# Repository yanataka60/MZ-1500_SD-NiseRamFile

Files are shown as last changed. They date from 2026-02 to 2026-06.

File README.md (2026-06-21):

# MZ-1500_SD+偽RAMFILE複合ボード

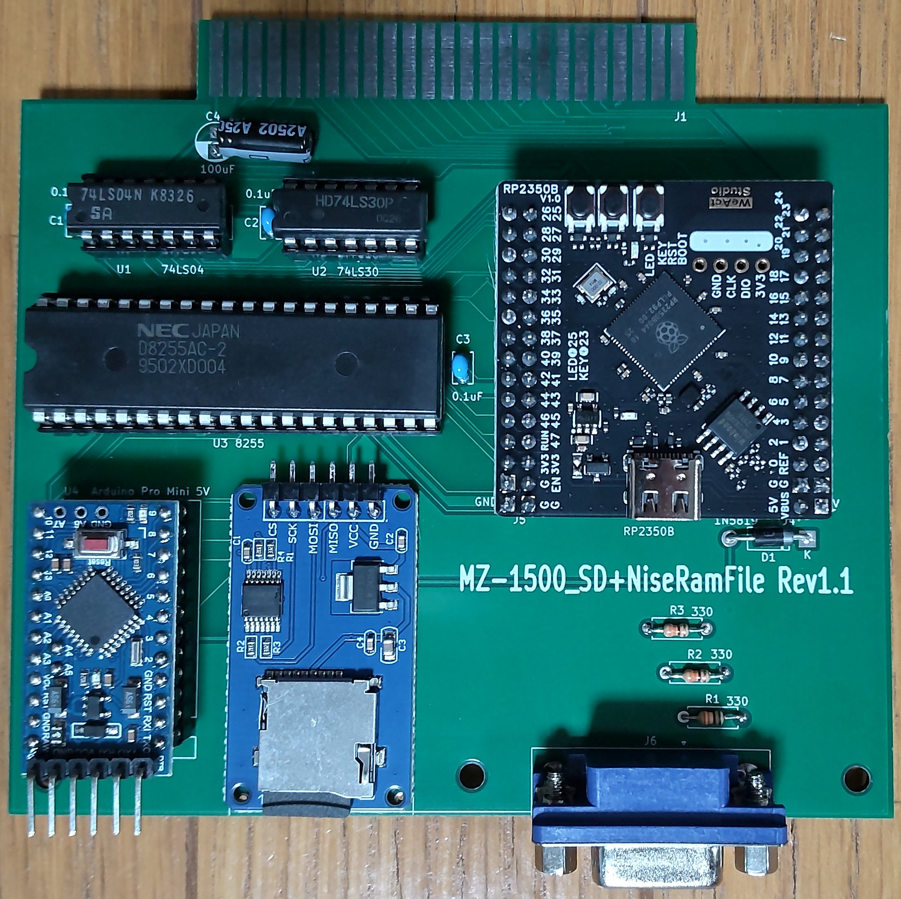
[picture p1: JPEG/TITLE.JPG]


しっぽいいんちょさんが作られた「偽RAMFILE for MZ-1500」とMZ-1500_SDを合体させたボードです。

MZ-1500_SD: https://github.com/yanataka60/MZ-1500_SD

偽RAMFILE for MZ-1500: https://github.com/shippoiincho/niseramfile

偽RAMFILE for MZ-1500のMZ-1R12 SRAMメモリをMZ-1500_SD起動用に使うことで一枚のボードにまとめています。

機能の詳細についてはそれぞれのウェブページを参照してください。

## 回路図
　KiCadフォルダ内のMZ-1500_SD+NRF.pdfを参照してください。

[回路図](https://github.com/yanataka60/MZ-1500_SD-NiseRamFile/blob/main/Kicad/MZ-1500_SD%2BNRF.pdf)

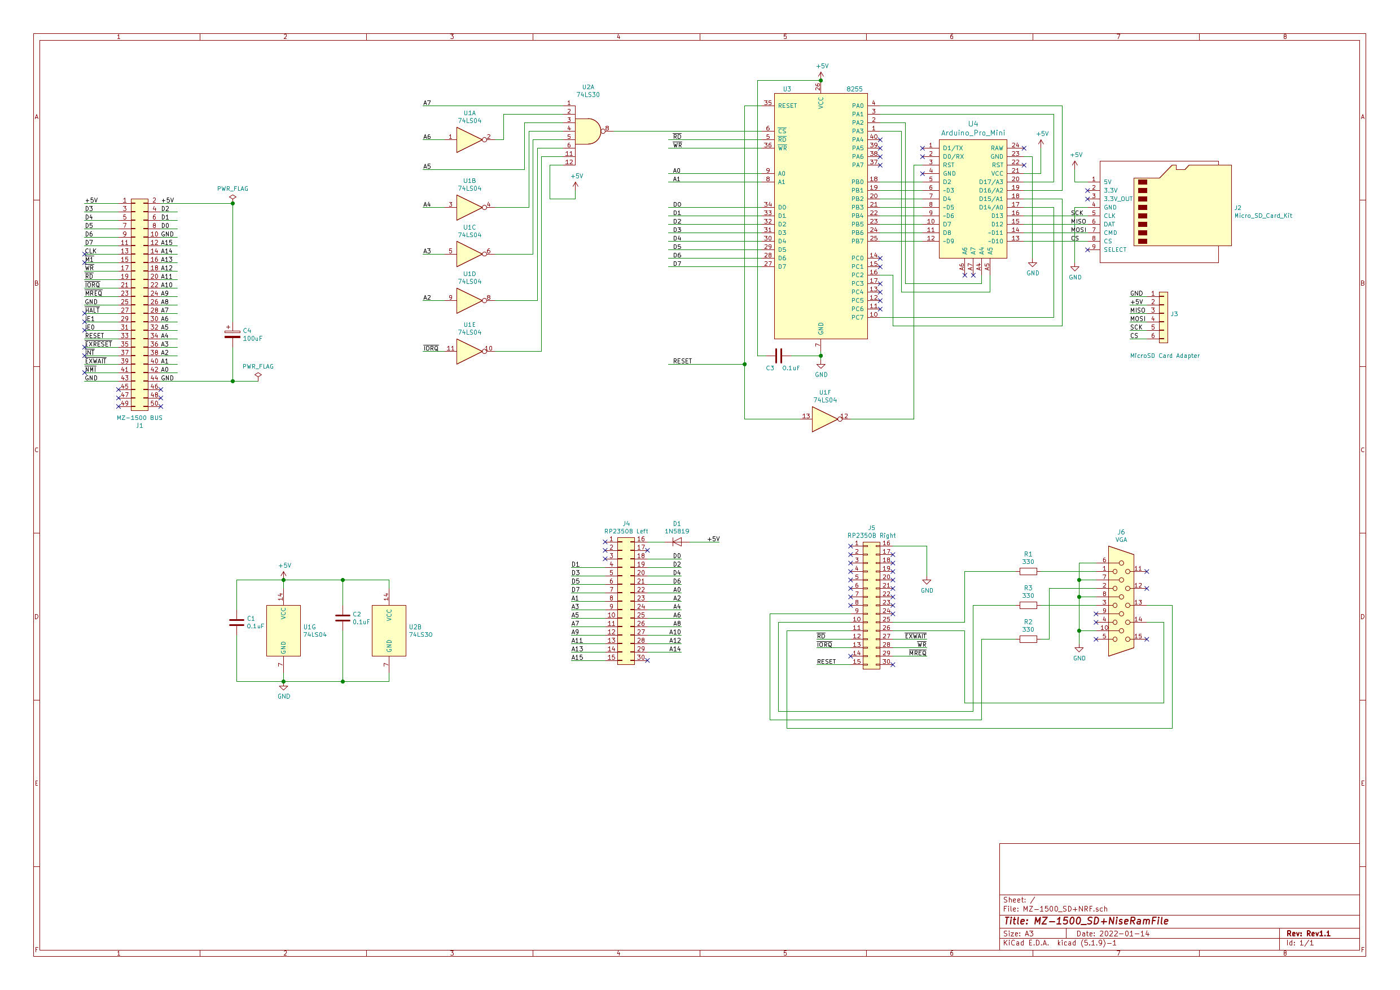
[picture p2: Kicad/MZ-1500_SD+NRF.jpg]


|番号|品名|数量|備考|
| --- | --- | --- | --- |
||J2、J3のいずれか|||
|J2|Micro_SD_Card_Kit|1|秋月電子通商 AE-microSD-LLCNV (注1)|
|J3|MicroSD Card Adapter|1|Arduino等に使われる5V電源に対応したもの(注3)|
|J4,J5|ピンソケット2x15Pin|2|RP2350Bマイコンボード用,秋月電子通商 FHU-2x42SGなど|
|J6|VGA用基板ソケット 3列15ピン|1|マルツ DJ-VGA14.5など(注4)|
|U1|74LS04|1||
|U2|74LS30|1||
|U3|8255|1||
|U4|Arduino_Pro_Mini_5V|1|Atmega328版を使用 168版は不可。(注2)|
||RP2350Bボード(Raspberry Pi Pico 2)|1|Amazon WA00021 RP2350Bマイコンボードなど|
|C1-C3|積層セラミックコンデンサ 0.1uF|3||
|C4|電解コンデンサ 16v100uF|1||
|D1|ダイオード 1N5819|1||
|R1-R3|カーボン抵抗 330Ω|3||
||ピンヘッダ|2Pin分|Arduino_Pro_MiniにはA4、A5用のピンヘッダが付いていないため別途調達が必要です 秋月電子通商 PH-1x40SGなど|
||ピンソケット(任意)|26Pin分|Arduino_Pro_Miniを取り外し可能としたい場合に調達します 秋月電子通商 FHU-1x42SGなど|

　　　注1)秋月電子通商　AE-microSD-LLCNVのJ1ジャンパはショートしてください。

　　　注2)Arduino Pro MiniはA4、A5ピンも使っています。

　　　注3)MicroSD Card Adapterを使う場合

　　　　　J3に取り付けます。

MicroSD Card Adapterについているピンヘッダを除去してハンダ付けするのが一番確実ですが、J3の穴にMicroSD Card Adapterをぴったりと押しつけ、裏から多めにハンダを流し込むことでハンダ付けをする方法もあります。なお、この方法の時にはしっかりハンダ付けが出来たかテスターで導通を確認しておいた方が安心です。

ハンダ付けに自信のない方はJ2の秋月電子通商　AE-microSD-LLCNVをお使いください。AE-microSD-LLCNVならパワーLED、アクセスLEDが付いています。

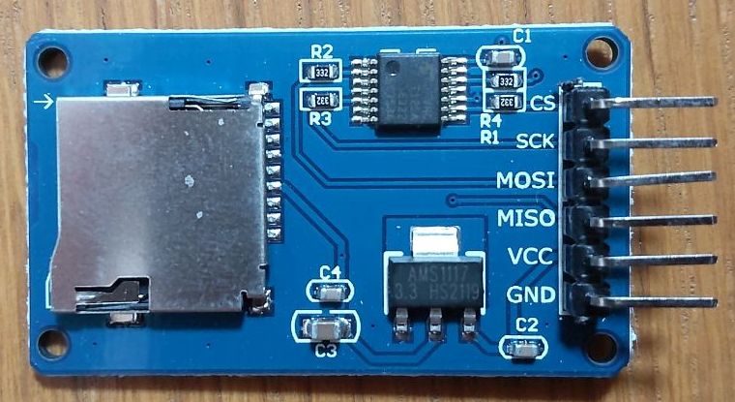
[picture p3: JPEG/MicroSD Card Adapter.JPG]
MicroSD Card Adapter1


　　　注4)VGA用基板ソケットには、ピン間隔の異なるものがあるようです。マルツ DJ-VGA14.5ではないものを購入する場合はこちらで寸法を確認してください。

　　　https://www.marutsu.co.jp/contents/shop/marutsu/datasheet/DJ-VGA14.5.pdf

## 偽RAMFILE for MZ-1500の修正
　MZ-1500_SDの起動にはMZ-1R12 SRAMメモリを利用しますが、オリジナルの偽RAMFILE for MZ-1500では電源投入時MZ-1R12 SRAMメモリのチェックでChecksum Errorで止まるようになっていますので電源投入時にMZ-1R12 SRAMメモリから起動できるように修正が必要です。

　niseramfile.cの523行あたりに

//    memcpy(mz1r12,romslots,0x8000);

    memset(mz1r12,0xaa,0x8000);

　となっている個所を

    memcpy(mz1r12,romslots,0x8000);

//    memset(mz1r12,0xaa,0x8000);

　とコメントアウトを修正し、再コンパイルします。

　出来上がったniseramfile.uf2をRP2350Bマイコンボードに書き込みます。

　なお、2026.2.5時点のソースを修正、再コンパイルしたniseramfile.uf2をRP2350Bフォルダに置いてあります。

https://github.com/yanataka60/MZ-1500_SD-NiseRamFile/tree/main/RP2350B

## MZ-1500_SD BOOT PROGRAMをMZ-1R12 SRAMメモリ 0番バックアップスロットへ書き込み
　MZ-1500_SDリポジトリEMMフォルダ内の1Z-009B_SD_Launcher.binをMZ-1R12 SRAMメモリ 0番バックアップスロットへ書き込んでください。

https://github.com/yanataka60/MZ-1500_SD/blob/main/EMM/1Z-009B_SD_Launcher.bin

　書き込み方の詳細は偽RAMFILE for MZ-1500を参照してください。

https://github.com/shippoiincho/niseramfile/tree/main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

　なお、書き込みにpicotool.exeを利用する場合には以下のウェブページ右側の「Releases」からダウンロードできます。

https://github.com/raspberrypi/pico-sdk-tools

## Arduinoプログラム
　MZ-1500_SDを参照してください。

https://github.com/yanataka60/MZ-1500_SD/tree/main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

## 運用の注意点
　偽RAMFILE for MZ-1500のEMMは自動的にバックアップされません。

　電源ON時に0番EMMスロットの内容が自動的にEMMにLOADされますが、電源OFF時にEMMの内容は消滅します。

　EMMの内容を書き込み・修正等した場合にはEMMの内容をスロットに書き込む動作を行う必要があります。

https://github.com/shippoiincho/niseramfile/tree/main?tab=readme-ov-file#pio-3034-emm

## EMMからの起動
　「EMM0」に起動可能なMZ-700用HuBASICが存在している場合MZ-1500_SDからコマンド「FDE0」を実行することで「EMM0」のMZ-700用HuBASICから起動可能です。

　なお、EMMの00000番地が「01h」でなければEMMからの起動はせずにコマンド待ちに戻りますが、00000番地以降に異常があってもチェックはしていないので最悪暴走します。

　MZ-1500用HuBASIC、MZ-80K用HuBASICではEMMがサポートされていません。EMMが使えるのはMZ-700用HuBASICのみとなりますが、テープ版しかなくそのままではEMMにHuBASICの起動イメージを作成することが出来ません。

　BouKiCHiさんのHuDiskなどを使いMZ-700用HuBASICの起動ディスクイメージを作成したうえでEMMMENUのEMMLOADでEMMに書き込む必要があります。

## SAMPLEプログラム
　SAMPLEフォルダ内にEMMMENU2を置きました。

　使い方については、フォルダ内のREADME.mdを参照してください。

　SDからEMMへLOAD、EMMの内容をSDへSAVE、EMMスロットからEMMへLOAD、EMMの内容をEMMスロットへSAVEが使えます。

## 謝辞
　素晴らしい拡張モジュールを開発し、複合ボードの公開を快く承諾してくださったしっぽいいんちょさん、ありがとうございました。

## 追記
2026.3.1 MZ-1500_SDリポジトリEMMフォルダ内の1Z-009B_SD_Launcher.binがCHECKSUM計算前のファイルをアップしており、正常起動できませんでしたので更新しました。

2026.3.19 VGA用基板ソケットに注記を追加

2026.6.21 MZ-1500_SD+偽RAMFILE複合ボードに電源が供給されている状態でUSB-Cケーブルを接続してはいけない問題に対してすーぱーたーぼさんからご指摘いただいた対策を施しました。Rev1.0基板でも通常の使用でMZ-1500_SD+偽RAMFILE複合ボードに電源が供給されている状態でUSB-Cケーブルを接続することはありませんので通常使用においてRev1.0基板でも問題ありません。

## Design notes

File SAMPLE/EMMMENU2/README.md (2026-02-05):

# EMMMENU2(SDからEMMへLOAD、EMMの内容をSDへSAVE、EMMスロットからEMMへLOAD、EMMの内容をEMMスロットへSAVE) for MZ-1500_SD+偽RAMFILE複合ボード

MZ-1500_SD+偽RAMFILE複合ボードでEMMボートの内容をまるごとSDへSAVE、またSDにSAVEされたS-RAMの内容をまるごとEMMボートへLOAD、0～9番EMMスロットからEMMへLOAD、EMMの内容を0～9番EMMスロットへSAVEするプログラムです。

SDカードに保存されたEMM DUMPファイルはMZTファイルのヘッダが付加され320KB+128Byte=327808Byteになります。

なお、EMM DUMPファイルはWindowsパソコンのエミュレーターで利用可能であることを確認しています。

## 利用可能なエミュレーター

### TAKEDAさんのEmuZ-1500

https://takeda-toshiya.my.coocan.jp/

　EMM DUMPファイルから128Byteのヘッダを除去し、EMM.BINにリネームしてエミュレーターと同じフォルダに置けばエミュレーターから利用できるようになります。

　EmuZ-1500は、16MのEMM0として対応しているようです。EMM DUMPファイルから128Byteのヘッダを除去した327808Byteでも問題なく認識しますが、エミュレーターを終了させると16MByteのファイルとして再作成されます。

　16MByteとして作成されたEMM.BINに128Byteのヘッダをつけて拡張子をmztとすればEMM DUMPファイルとしてEMMLOADが可能です。(LOADされるのは先頭320kByte分のみ)

　この時、付加する128Byteのヘッダの内容はどんな内容でも構わないので00hを128Byte等好きにつけてください。

## EMMMENU2の使い方
　EMMMENU2.mztをSDカードに保存し、実行します。

　SD TO EMM LOAD、EMM TO SD SAVE、SLOT TO EMM LOAD、EMM TO SLOT SAVE、EXITを数字で選択します。

### SD TO EMM LOAD
　SDからEMMへの転送にかかる時間は約95秒です。

　起動すると「FNAME:」と聞いてきますので次のうちから選択して入力します。

#### [SHIFT+BREAK]キー
　処理が中断されたものとしてMONITOR入力待ちに戻ります。

#### DOSファイル名を入力せずそのまま[CR]キー
　選択したEMMに対応するPIO3034_0.mztをDOSファイル名としてSDカードからEMMに転送します。

#### DOSファイル名を入力して[CR]キー
　入力されたDOSファイル名のファイルをSDカードからEMMに転送します。拡張子の「mzt」は省略可能です。

#### *FDL xxx[CR]キー
　SDカードに保存されている文字列xxxから始まるDOSファイル名を一覧表示します。xxxを省略した場合はすべてのファイルが一覧表示対象となります。

　20件表示したところで指示待ちになるので打ち切るならSHIFT+BREAK又は↑を入力すると打ち切られ、Bキーで前の20件に戻ります。それ以外のキーで次の20件を表示します。

　検索結果の行頭には「FNAME:」を付加して表示してあるのでLOADしたいファイルにカーソルキーを合わせて[CR]キーを押すだけでLOADが可能です。

例)

FNAME:[CR]

FNAME:PIO-3034EMM0[CR]

FNAME:*FDL PIO[CR]

### EMM TO SD SAVE
　選択するとPIO3034-0-SAVE.mztというファイルがSDカードに作成されます。

　同名のファイルがあると上書きされます。SDに保存されるファイル名はPIO3034-0-SAVE.mztに固定されていて指定はできません。

　EMMからSDへの保存にかかる時間は約100秒です。

### SLOT TO EMM LOAD
　LOADするSLOT番号を0～9から選択します。偽RAMFILE for MZ-1500は0～31までのSLOTが使えますがEMMMENU2では簡略化しています。

　OK?と聞いてくるので良ければ「Y」、やめるなら「N」を入力します。

　ほぼ一瞬でLOADされます。

### EMM TO SLOT SAVE
　SAVEするSLOT番号を0～9から選択します。偽RAMFILE for MZ-1500は0～31までのSLOTが使えますがEMMMENU2では簡略化しています。

　OK?と聞いてくるので良ければ「Y」、やめるなら「N」を入力します。

　MZ-1500本体のRGB出力ではほぼ一瞬で終了しますが、偽RAMFILE for MZ-1500のVGA出力は数秒画面が乱れる・止まるなどしたのちに画面が回復します。

　偽RAMFILE for MZ-1500のVGA出力のみで運用している場合には画面が乱れてもあわてずにしばらくお待ちください。

### 追記
　MZ-2000_SD用のEMMSAVEで時々失敗することがあり、失敗するとMZ-2000_SDからSDカードにアクセス不可能になってしまう事象が発生します。

　こちらのMZ-1500_SD+偽RAMFILE複合ボード用EMMSAVE2では今のところ発生していませんが、もし発生した場合の復旧方法は以下の通りです。なお、SDカードに多くのファイルが登録されていると発生する可能性が高い気がします。

　EMMSAVE2を実行するときは必要最小限のファイル(EMMMENU2.MZT)だけが登録された専用のSDカードで実行でしてみてください。

　MZ-1500_SD+偽RAMFILE複合ボードからアクセス不可能になったSDカードもWindowsからは問題なくアクセスできるのでSDカードから作成に失敗したPIO3034-0-SAVE.mztを削除したのちにすべての内容を一旦Windowsのフォルダに移動させ、SDカードにファイルが一つもない状態にしてから退避したWindowsのフォルダからすべてのファイルを戻すことで復旧できます。

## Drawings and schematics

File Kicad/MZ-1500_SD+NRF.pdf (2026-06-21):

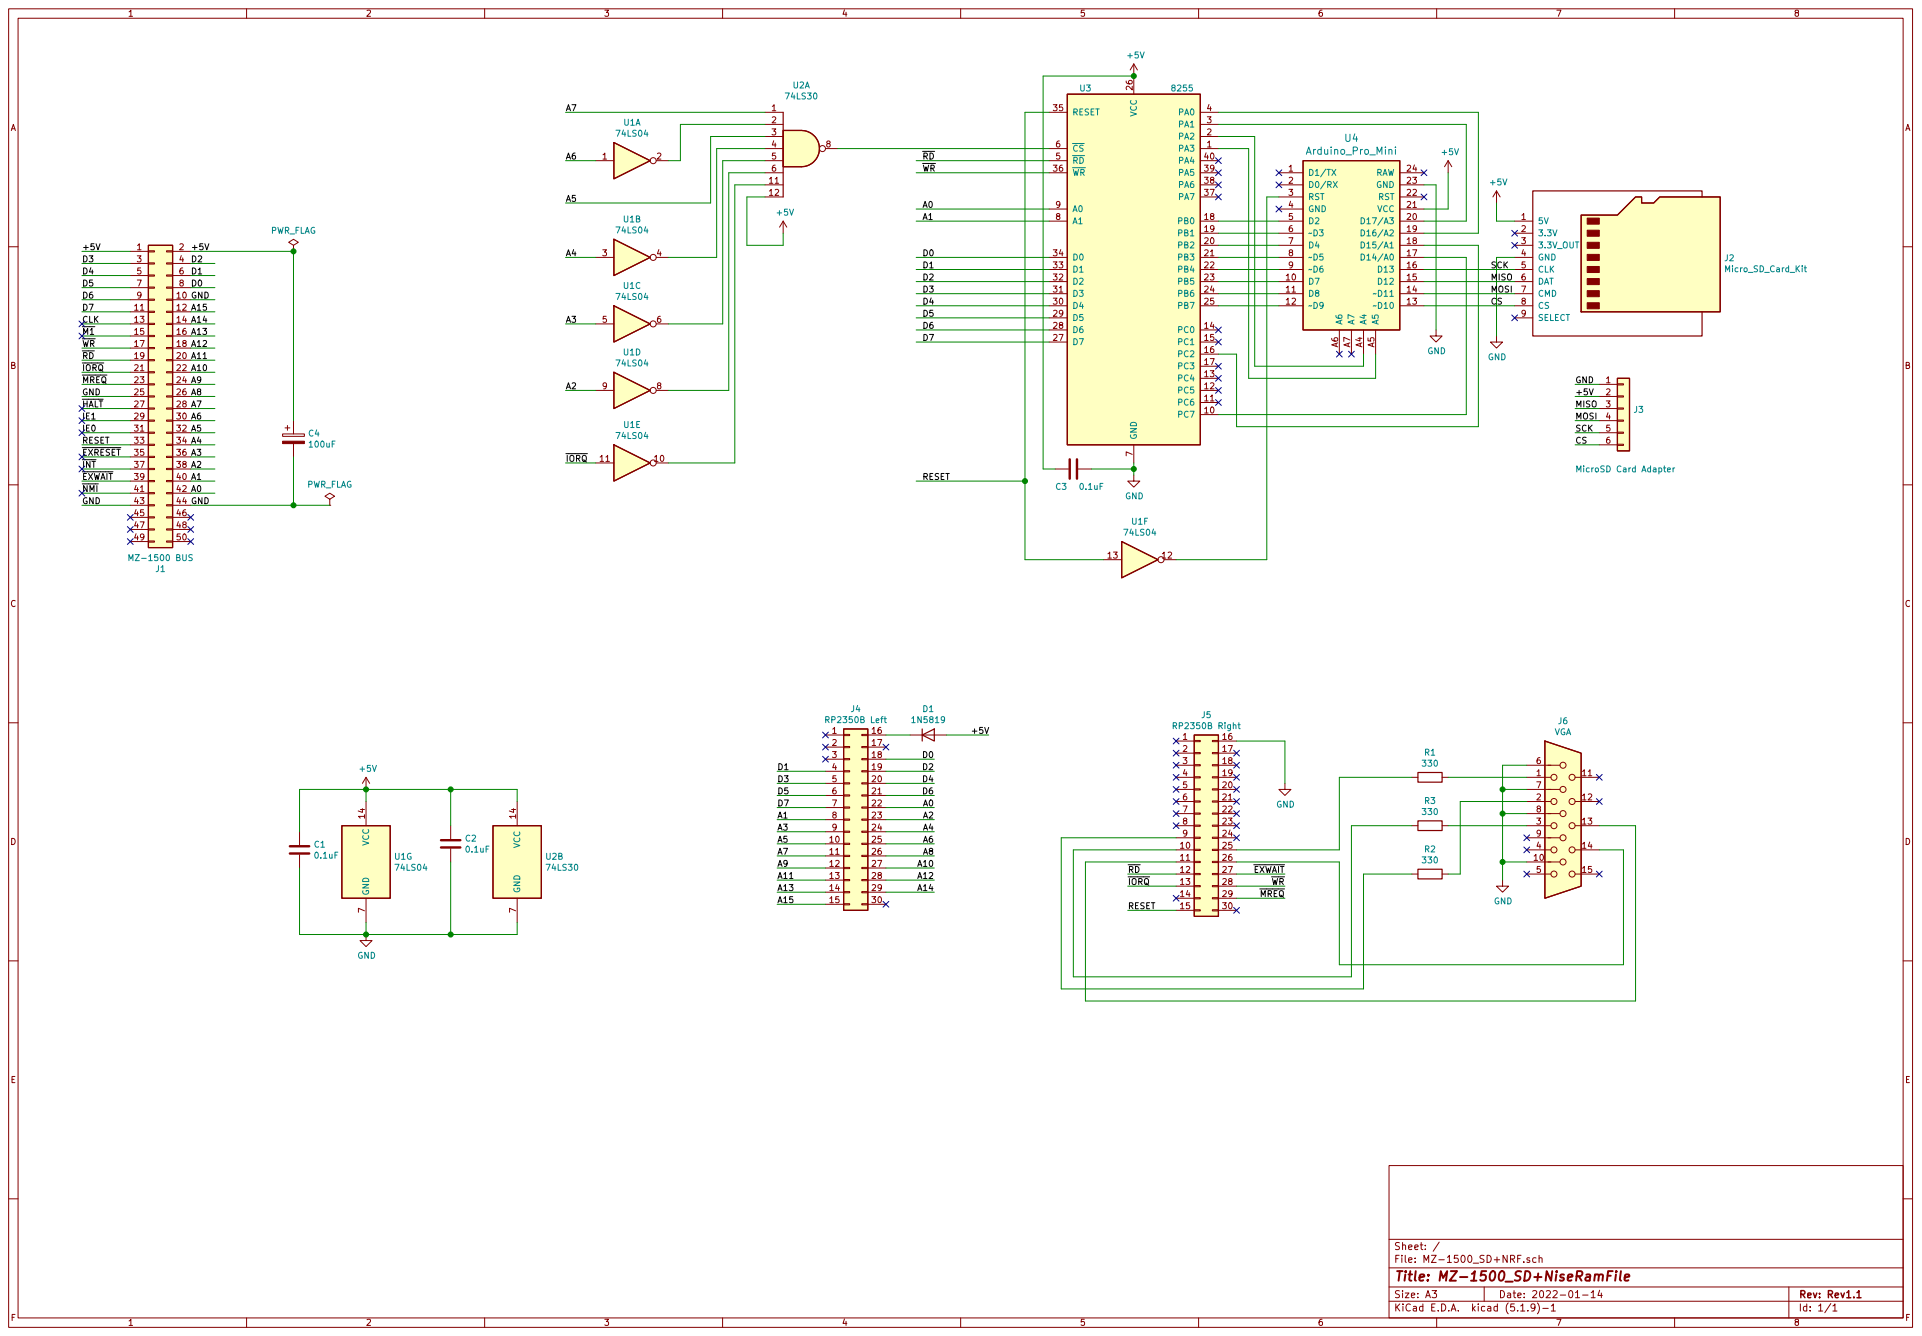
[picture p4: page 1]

J3 MicroSD Card Adapter +5V GND

File: MZ-1500_SD+NRF.sch Sheet: / VCC 14 GND

10 | 25
11 | 26

Id: 1/1 Title: MZ-1500_SD+NiseRamFile

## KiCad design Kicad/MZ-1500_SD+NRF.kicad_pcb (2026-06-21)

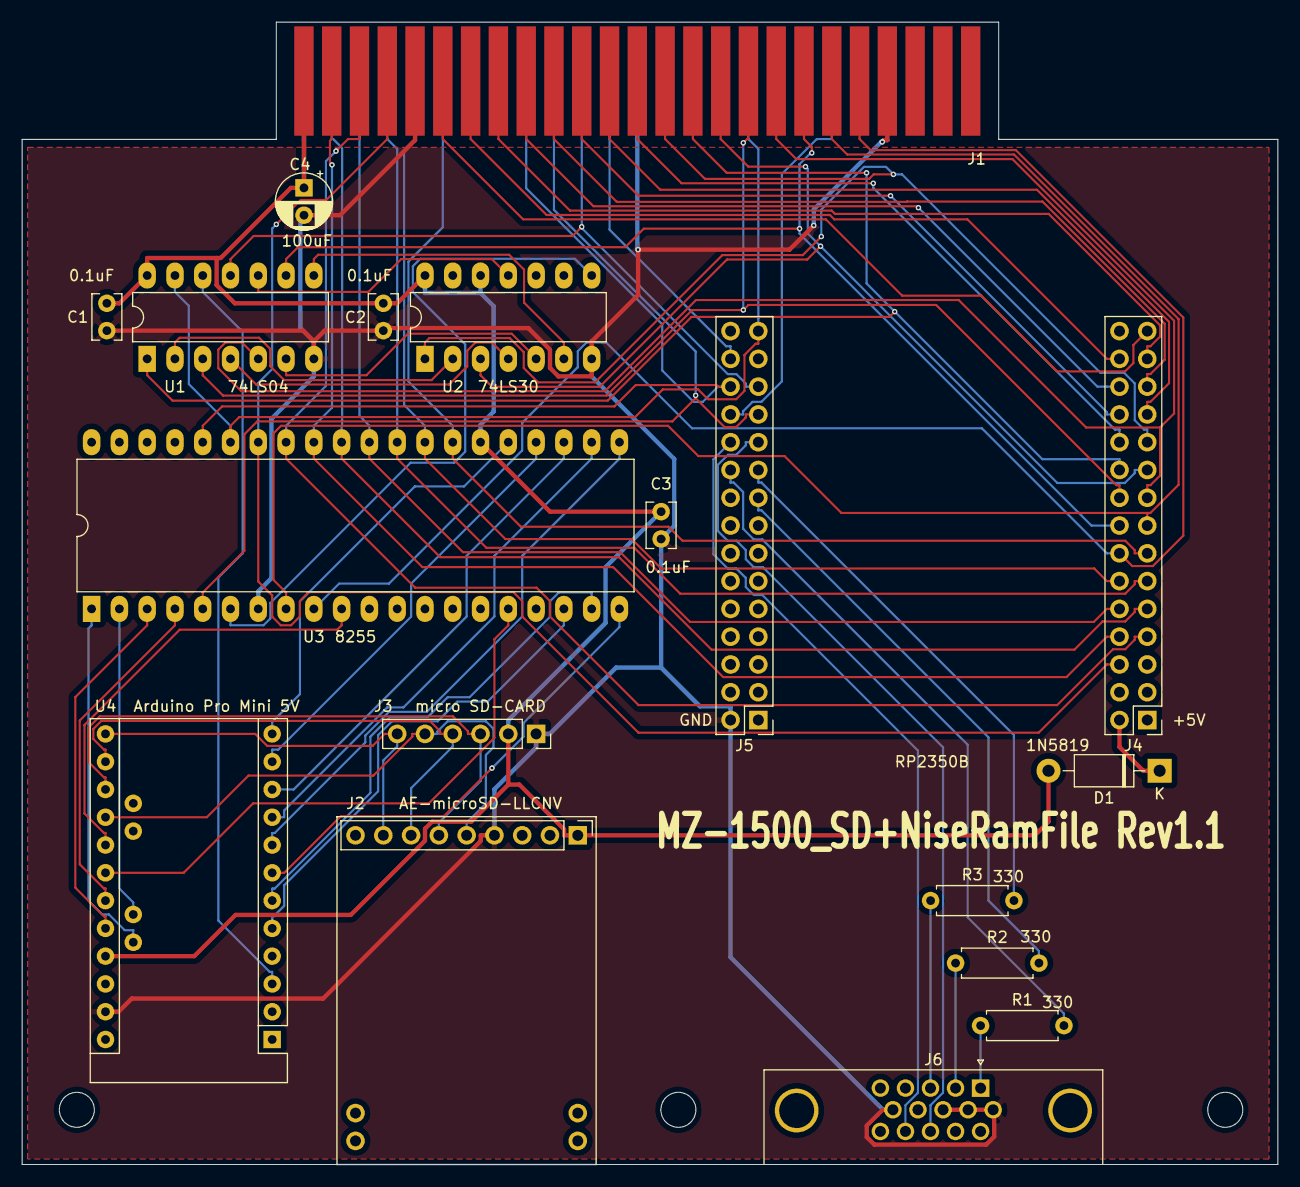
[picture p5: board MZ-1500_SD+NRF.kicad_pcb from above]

Board: 2 copper layers, 114.8 x 104.4 mm, 21 parts (0 on the bottom side), 66 nets.

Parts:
C1, C2, C3: 0.1uF; C_Rect_L4.0mm_W2.5mm_P2.50mm
C4: 100uF; CP_Radial_D5.0mm_P2.50mm
D1: BAT54; D_DO-41_SOD81_P10.16mm_Horizontal
J1: MZ-1500 BUS; BUS_50Pin
J2: Micro_SD_Card_Kit; AE-microSD-LLCNV
J3: MicroSD Card Adapter; PinSocket_1x06_P2.54mm_Vertical
J4: RP2350B Left; PinHeader_2x15_P2.54mm_Vertical
J5: RP2350B Right; PinHeader_2x15_P2.54mm_Vertical
J6: VGA; DSUB-15-HD_Female_Horizontal_P2.29x1.98mm_EdgePinOffset3.03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
MH1, MH2, MH3: MountingHole_3.2mm_M3
R1, R2, R3: 330; R_Axial_DIN0207_L6.3mm_D2.5mm_P7.62mm_Horizontal
U1: 74LS04; DIP-14_W7.62mm_LongPads
U2: 74LS30; DIP-14_W7.62mm_LongPads
U3: 8255; DIP-40_W15.24mm_LongPads
U4: Arduino_Pro_Mini

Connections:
+5V: C1.1, C2.1, C3.1, C4.1, D1.2, J1.1, J1.2, J2.1, J3.2, U1.14, U2.12, U2.14, U3.26, U4.21
/A0: J1.42, J4.22, U3.9
/A1: J1.40, J4.8, U3.8
/A2: J1.38, J4.23, U1.9
/A3: J1.36, J4.9, U1.5
/A4: J1.34, J4.24, U1.3
/A5: J1.32, J4.10, U2.3
/A6: J1.30, J4.25, U1.1
/A7: J1.28, J4.11, U2.1
/A8: J1.26, J4.26
/A9: J1.24, J4.12
/A10: J1.22, J4.27
/A11: J1.20, J4.13
/A12: J1.18, J4.28
/A13: J1.16, J4.14
/A14: J1.14, J4.29
/A15: J1.12, J4.15
/CS: J2.8, J3.6, U4.13
/D0: J1.8, J4.18, U3.34
/D1: J1.6, J4.4, U3.33
/D2: J1.4, J4.19, U3.32
/D3: J1.3, J4.5, U3.31
/D4: J1.5, J4.20, U3.30
/D5: J1.7, J4.6, U3.29
/D6: J1.9, J4.21, U3.28
/D7: J1.11, J4.7, U3.27
/MISO: J2.6, J3.3, U4.15
/MOSI: J2.7, J3.4, U4.14
/RESET: J1.33, J5.15, U1.13, U3.35
/SCK: J2.5, J3.5, U4.16
/~EXWAIT: J1.39, J5.27
/~IORQ: J1.21, J5.13, U1.11
/~MREQ: J1.23, J5.29
/~RD: J1.19, J5.12, U3.5
/~WR: J1.17, J5.28, U3.36
GND: C1.2, C2.2, C3.2, C4.2, J1.10, J1.25, J1.43, J1.44, J2.4, J3.1, J5.16, J6.6, J6.7, J6.8, J6.10, U1.7, U2.7, U3.7, U4.23
unnamed: D1.1, J4.16
unnamed: J5.9, R2.2
unnamed: J5.10, R3.2
unnamed: J5.11, J6.13
unnamed: J5.25, R1.2
unnamed: J5.26, J6.14
unnamed: J6.1, R1.1
unnamed: J6.2, R2.1
unnamed: J6.3, R3.1
unnamed: U1.2, U2.2
unnamed: U1.4, U2.4
unnamed: U1.6, U2.5
unnamed: U1.8, U2.6
unnamed: U1.10, U2.11
unnamed: U1.12, U4.3
unnamed: U2.8, U3.6
unnamed: U3.1, U4.A5
unnamed: U3.2, U4.A4
unnamed: U3.3, U4.20
unnamed: U3.4, U4.19
unnamed: U3.10, U4.17
unnamed: U3.16, U4.18
unnamed: U3.18, U4.5
unnamed: U3.19, U4.6
unnamed: U3.20, U4.7
unnamed: U3.21, U4.8
unnamed: U3.22, U4.9
unnamed: U3.23, U4.10
unnamed: U3.24, U4.11
unnamed: U3.25, U4.12
